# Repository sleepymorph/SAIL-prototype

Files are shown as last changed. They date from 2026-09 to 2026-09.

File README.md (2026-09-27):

<p align="center">
<picture>
  <source media="(prefers-color-scheme: dark)" srcset="LOGO/black.png">
  <source media="(prefers-color-scheme: light)" srcset="LOGO/white.png">
  SAIL THE PROTOTYPE LOGO
</picture>
 </p>

<h1 align="center"><b>SAIL THE PROTOTYPE</b></h1>

<div align="center">





</div>

---

**SAIL The Prototype** is a [DMP](https://en.wikipedia.org/wiki/Digital_media_player), an open-source project that aims to become a startup. This is not a basic digital media player, but also a multi-tool. It has 433MHZ CC1101, [Infrared LED](https://www.lcsc.com/product-detail/C18199783.html), and NFC functions(13.56MHZ). 
The STM32H723 is a powerful MCU for that project, I would say it is even an overkill. 

Hardware Architecture:
  1. Main Board: Houses the STM32, ESP32, Display, and user input interfaces
  2. NFC Board: Contains the NFC circuitry, CC1101(currently 433 MHZ only), and magnetic pogo pin connectors
  3. Infrared Board: Dedicated to IR Transceiver

The goal of the project is to combine multi-tool device with a music player, making you less addicted and helps you to escape social media & algorithms(bad ones).

|*MAIN Board* Top Component Layer |*MAIN Board* Bottom Component Layer |  
|  :--- | :--- |
| |  |

---

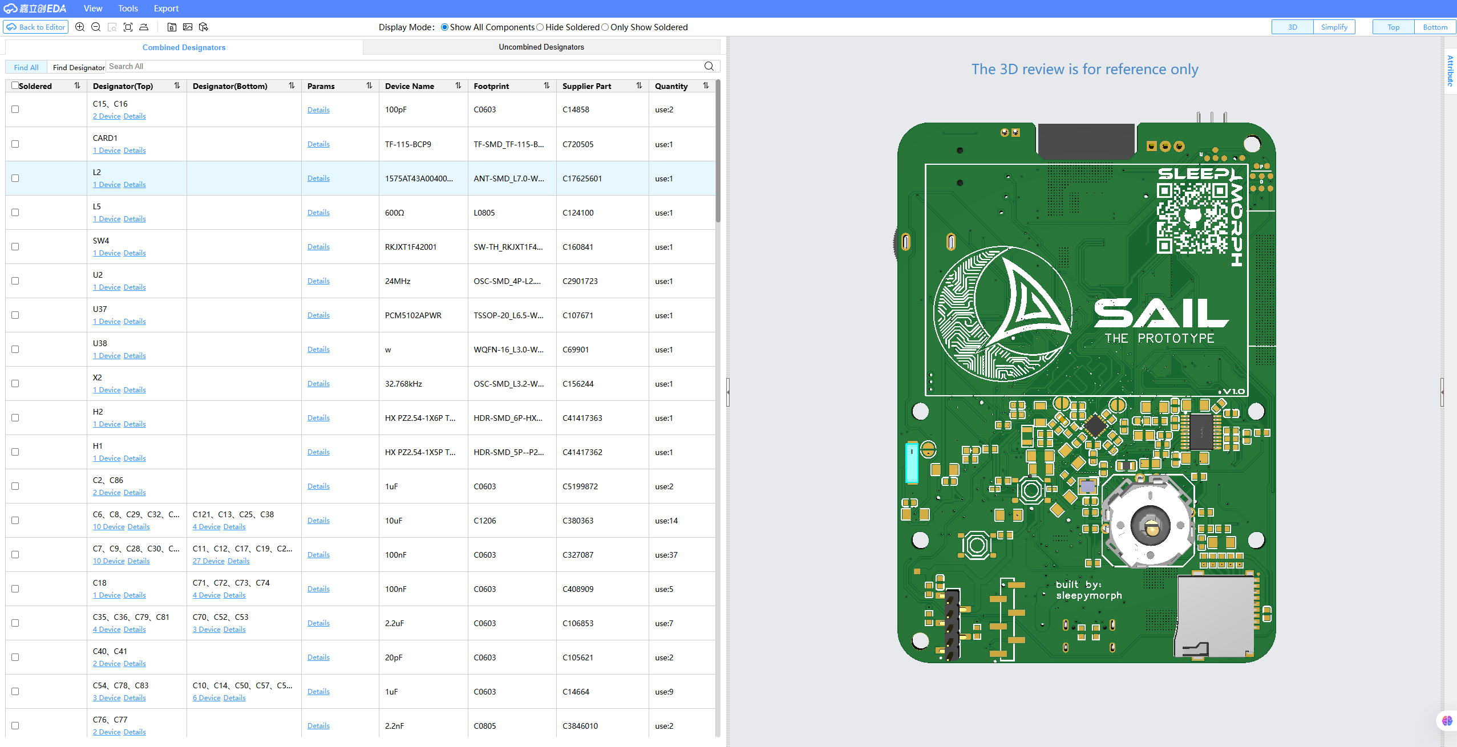
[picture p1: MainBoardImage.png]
Click me! (https://sail-mocha.vercel.app)

<p align="center">
    <b>Click the picture to see MAIN Board IBOM!</b>
  </a>
</p>

---

So, lets get into the details. First of all, lets talk about what you see here the most, to be exact - the user input devices.

The most valuable thing you can see here is probably the big [encoder](https://www.lcsc.com/product-detail/C160841.html). The encoder is pretty cool, its being used widely, especially at the automotive solutions. 

Its a 5-way button + encoder functions, to be exact its going 5 directions(X+, Y+, X-, Y-), pressing down, scrolling phase A and B. Next thing are 2 buttons, I still have no clue what I will use them for, but probably next song - previous song.

The most hidden, but probably the coolest thing of the device is the [thumb potentiometer](https://www.lcsc.com/product-detail/C351175.html), its placed at the left edge of the board, next to the left end to the display. 

---
<h1 align="center"><b>NFC Board</b></h1>

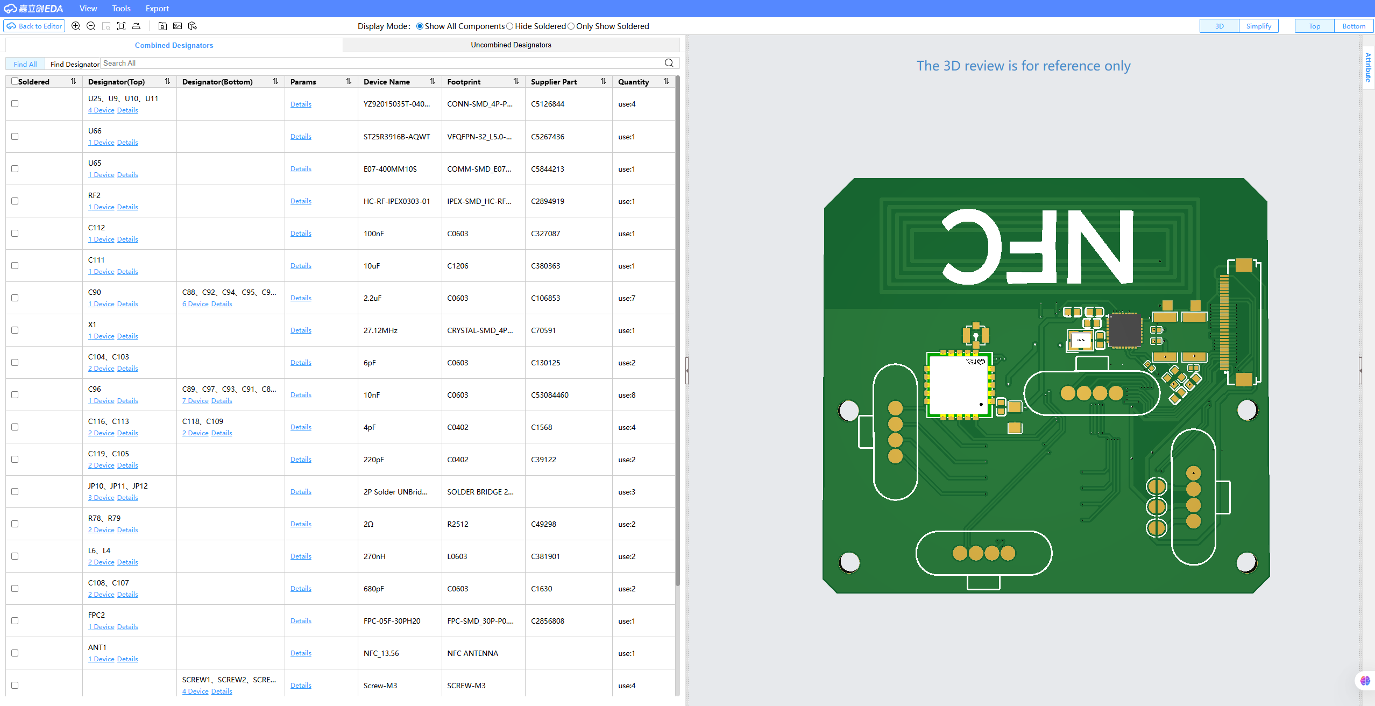
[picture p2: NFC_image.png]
Click me! (https://ibom-nfc.vercel.app/)

<p align="center">
    <b>Click the picture to see the NFC PCB IBOM!</b>
  </a>
</p>

--- 

NFC Board that contains half out of all of the functionality of the device --

It has NFC, CC1101 *433 MHz only yet*, and as a juicy cherry on a chocolate dry cake -
magnetic pogo pins for a breakout board. Here is the pinout if you would like to make a breakout board 

Untitled-2026-04-23-1610 excalidraw

| Pin on the board| IO on the ESP32|
| --- | --- |
| CS1: | IO32 |
| CS2: | IO33 |
| CS3: | IO4  |
| CS4: | IO15 |
| | |
| MOSI: | IO23 |
| MISO: | IO19 |
| SCK:  | IO18 |
| CS: | - |
| | |
| SDA: | IO21 |
| SCL: | IO22 |
---
<h1 align="center"><b>Infrared board</b></h1>

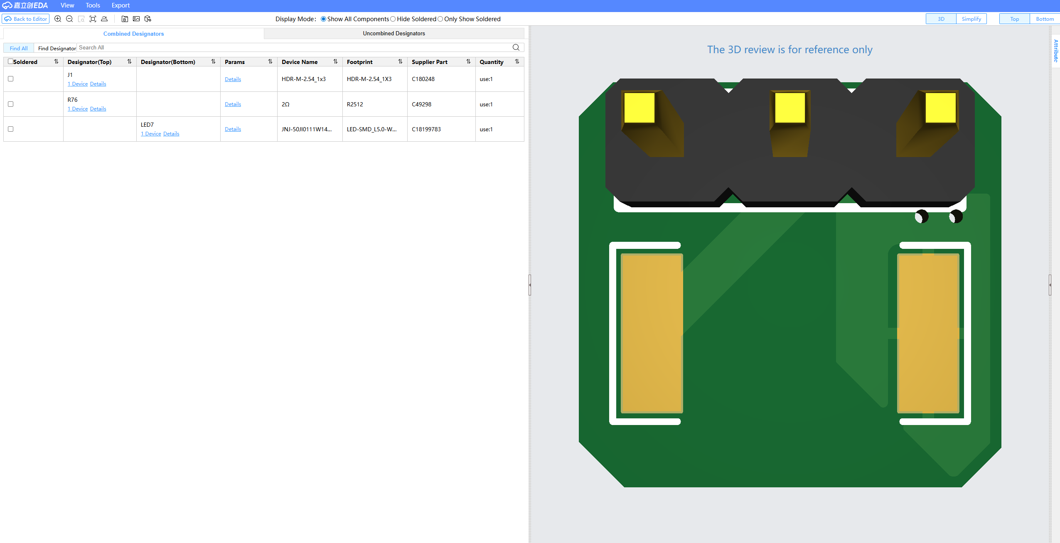
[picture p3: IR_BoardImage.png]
Click me! (https://ibom-ir.vercel.app/)

<p align="center">
    <b>Click the picture to see the Infrared PCB IBOM!</b>
  </a>
</p>

---

I couldnt find any good IR Transceiver which was right angled, so instead I found a really good SMD 5050 LED, its powerful enough to remote something from the distance of 15m *by my calculations*

---
# 3D Design:

Here is an image how it looks from the side, I explained a big rectangular right there and a strange looking knob right there too


---

# Fusion360 Render:



**The 3D files are in the Release folder since GitHub didnt want to accept files >25MB, there are 2 files, a Knob and fully assembled PCB(No casing yet)**

---

<h1 align="center"><b>More details and summary</b></h1>

| **Feature** | **Details** |
|---|---|
| **Main MCU** | STM32H723 as a main MCU that does all the work |
| **Secondary MCU** | ESP32-WROVER-IE(16MB) for BlueTooth headphones and pogo pin connectors(IOs) |
| **2.4" IPS TFT Display** | 2.4" IPS Display connected via FPC, 8080 16-bit protocol. [BuyDisplay](https://www.buydisplay.com/2-4-inch-ips-240x320-tft-lcd-display-capacitive-touch-screen) |
| **Multi-Tool features** | [NFC Module](https://www.lcsc.com/product-detail/C5267436.html), CC1101 *433 MHz ONLY*, IR Transceiver, Receiver |
| **RTC** | BS-CR2032-8 battery slot for [RTC functionality](https://www.lcsc.com/product-detail/C9866.html), and MAX-M10S-00B(GPS component) for RTC Syncing |
|	~~**Metal Body**~~ | ~~Aluminium front and back plate; 3D-printed middle section~~ *plan for future* |
| **Power and file transmitting** | USB-C Port which allows high speed data transfer(up to 50MB/s) with help of [USB3300](https://www.lcsc.com/product-detail/C108954.html) , and of course power delievery |
| **Battery Type** | 2500mAh Li-Po battery, 505065, [Aliexpress](https://www.aliexpress.com/item/1005009908189503.html) |
| **Battery Life** | ~8 hours idle, 4-5 hours typical usage |
| **Battery Voltage Measurement** | ADC Technology, connected to pin PA0 of STM32H7 |
| **Magnet on Back Plate of NFC Board(Pogo pins)** | [4x 4-Pin Pogo pin connector](https://www.lcsc.com/product-detail/C5126844.html) is a female version. For a breakout board you would need this [magnetic connector](https://www.lcsc.com/product-detail/C5126845.html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)  |
| **Audio components** | [PCM5102APWR](https://www.lcsc.com/product-detail/C107671.html) as a DAC, [TPA6132A2RTER](https://www.lcsc.com/product-detail/C69901.html) as an AMP and a [PJ-327A 5JJ](https://www.lcsc.com/product-detail/C668605.html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) as a jack 3.5mm connector for headphones. |  
| **Dimensions** | 70x100x25mm(W, L, H) which I find pretty solid(Only the PCB Assembled size), but I assume with a casing it would be with casing around 74x104x29mm(W, L, H)|
---

## .IOC


---

Questions or need more info? Reach out to me!\
Discord: **Sleepymorph**\
Telegram: **@ifyouask3d**

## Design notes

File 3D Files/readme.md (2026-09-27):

Assembled_PCB.rar contains a fully assembled PCB with no enclosure -- it has a knob, battery, 3 assembled boards and you can take a look at dimensions ^_^ 

ImageToStl com_Assembled_PCB stl

  1. 3D_NFC_*** - step file of NFC Board
  2. 3D_PCB5_*** - step file of IR Board
  3. MainPCB.zip - contains step file of Main Board

ImageToStl com_3D_PCB_MyOwnMP3_2026-04-27+(1) step

ImageToStl com_3D_NFC_2026-04-27 step

ImageToStl com_3D_PCB5_2026-04-27 step

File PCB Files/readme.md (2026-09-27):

This is a folder, containing a .zip file and .epcb
.zip file is to import the PCB to altium, and .epcb is a source file of the main PCB

Actually, .zip file(Altium) contains every file of the project, such as .schdoc and .pcbdoc

PCB_MyOwnMP3.pcbdoc - Main PCB Board
NFC.pcbdoc - NFC Board
PCB5.pcbdoc - IR Board

About .epcb I have no clue what you should do with it, but I have tested importing altium files into my EasyEDA Pro, and that worked quite well


Everything is good except the net port labels, I have no clue what happened to them:


Everything is also broken a little by little - the font didnt save, there is some strange PCB frame, some unknown 3D models, tho its not like that:


And there are 15650 DRC mistakes ...
Tho to fix all it takes is to recreate the ground plane 


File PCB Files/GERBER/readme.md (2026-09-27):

Gerber files here!

Explanation: 
  1. Gerber_PCB_MyOwnMP3_*** - Main Board
  2. Gerber_NFC_*** - NFC Board
  3. Gerber_PCB5_*** - IR Board

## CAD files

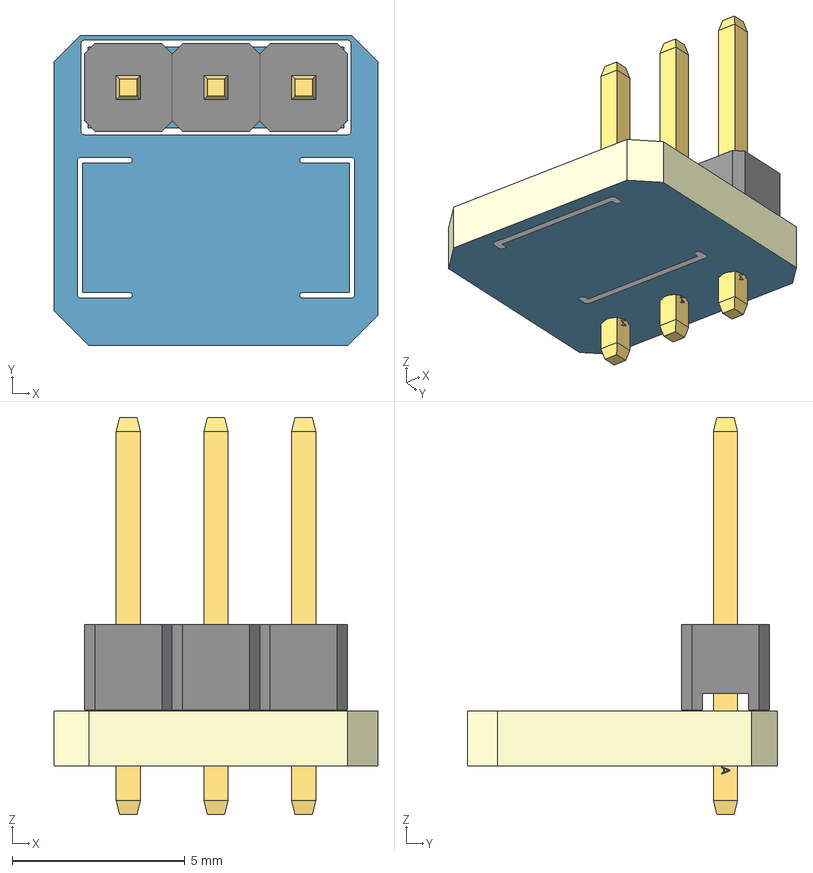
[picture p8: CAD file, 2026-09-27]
3D Files/3D_PCB5_2026-04-27.step
9.37 x 8.99 x 11.5 mm
Board~4CEo
TopCopper~4CEo
BottomCopper~4CEo
TopSilkscreen~4CEo
BottomSilkscreen~4CEo
TopFpcStiffener~4CEo
BottomFpcStiffener~4CEo
HDR-M-2.54_1X3~HDR-M-2.54_1x3~4CEo

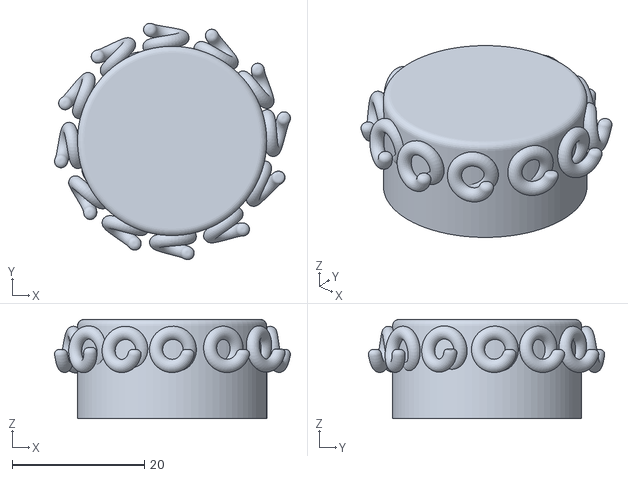
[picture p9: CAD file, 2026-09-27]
3D Files/Knob.stl
35.6 x 35.7 x 15.0

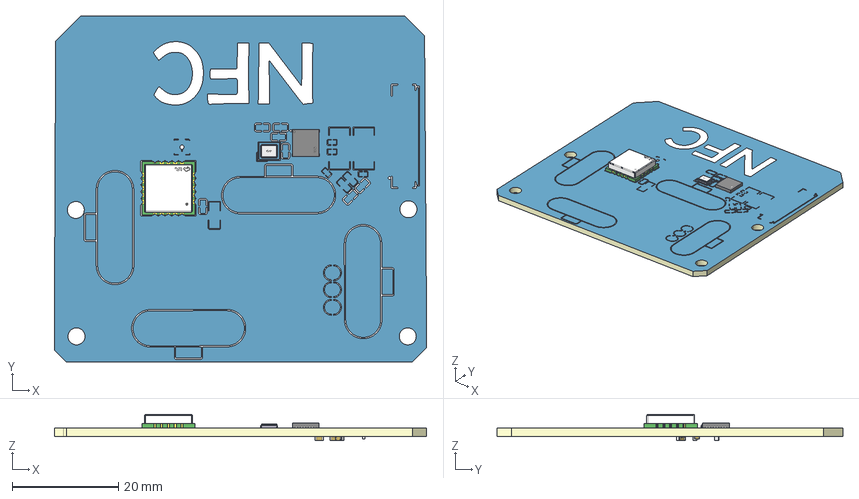
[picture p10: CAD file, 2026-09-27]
3D Files/3D_NFC_2026-04-27.step
70.0 x 65.0 x 4.92 mm
Board~R6V8
TopCopper~R6V8
BottomCopper~R6V8
TopSilkscreen~R6V8
BottomSilkscreen~R6V8
TopFpcStiffener~R6V8
BottomFpcStiffener~R6V8
C0603~C0603_L1.6-W0.8-H0.8~R6V8 x 3
C0402~C0402_L1.0-W0.5-H0.5~R6V8
CRYSTAL-SMD_4P-L3.2-W2.5-BL~CRYSTAL-SMD_4P-L3.2-W2.5-BL~R6V8
VFQFPN-32_L5.0-W5.0-P0.50-TL-EP3.5~VFQFPN-32_ L5.0-W5.0-P0.50-TL-EP3.5~R6V8
COMM-SMD_E07-400MM10S~COMM-SMD_E07-400MM10S~R6V8

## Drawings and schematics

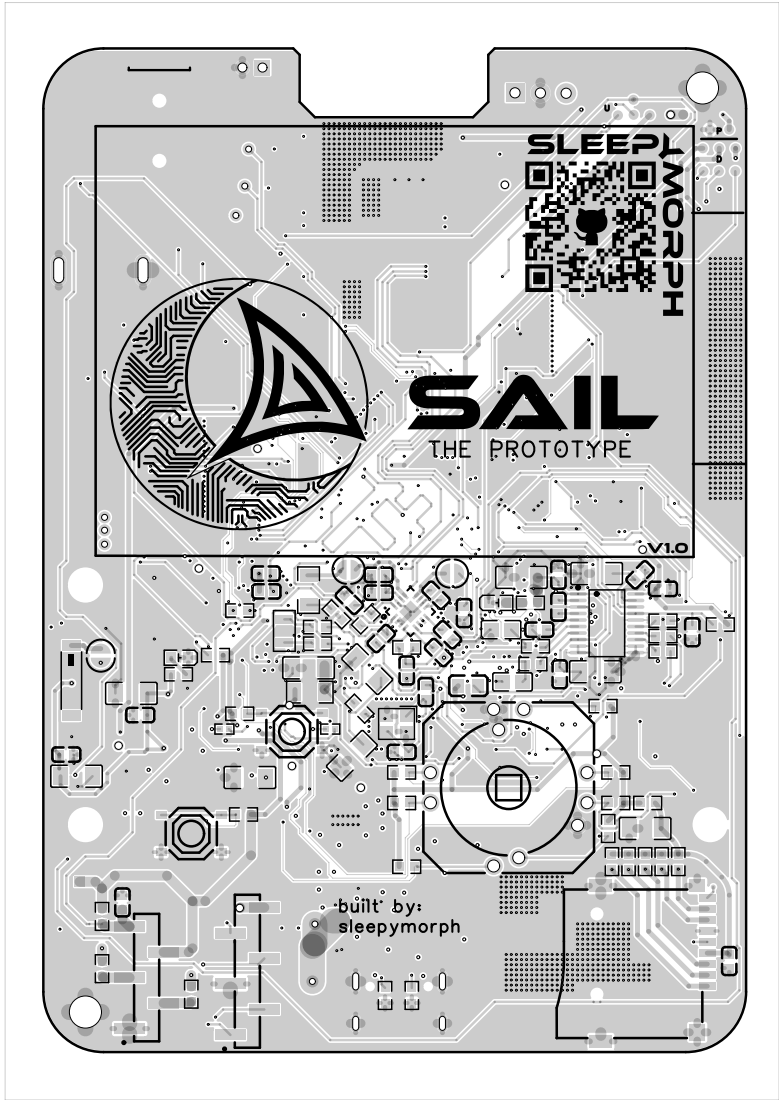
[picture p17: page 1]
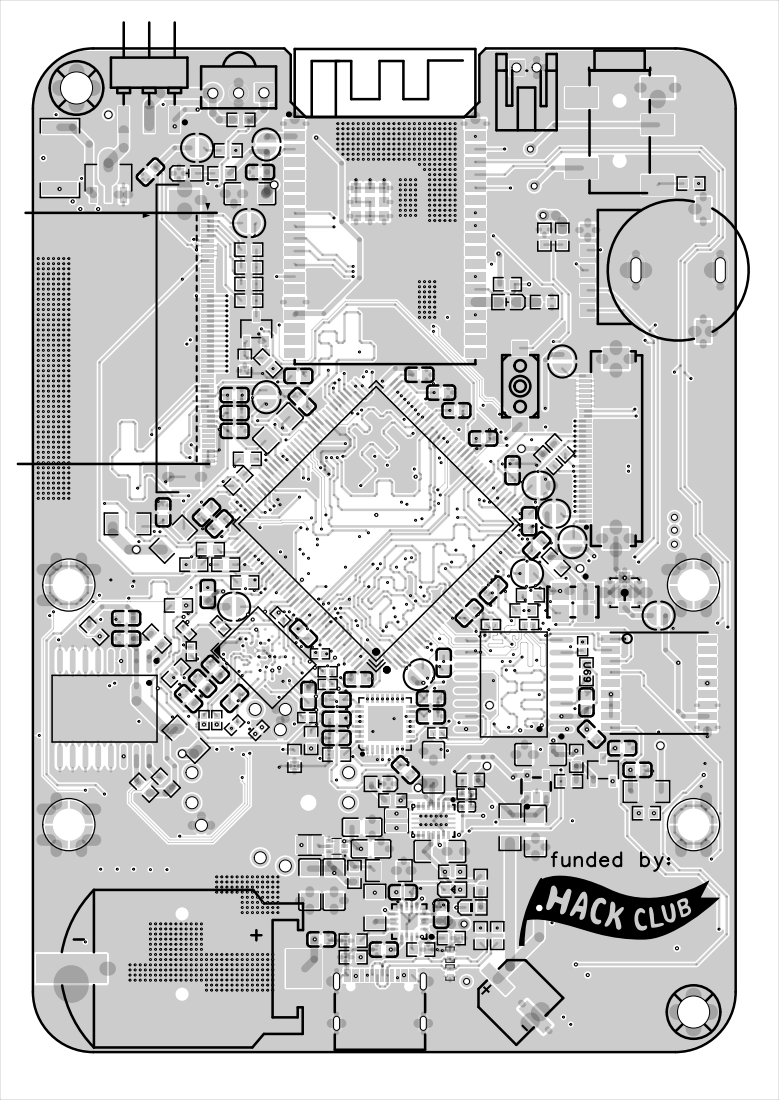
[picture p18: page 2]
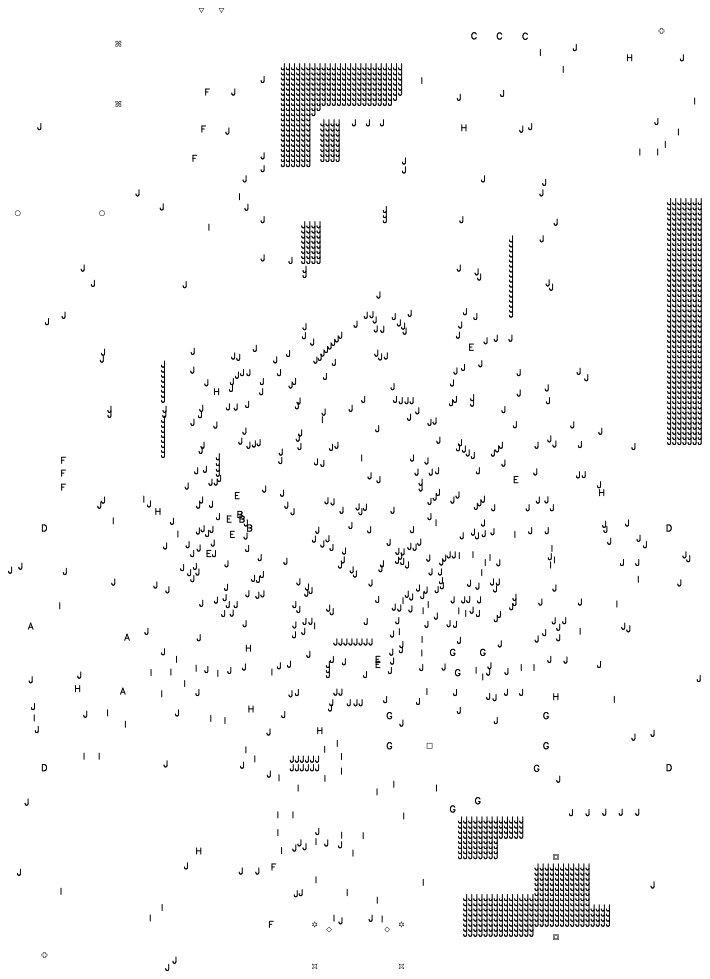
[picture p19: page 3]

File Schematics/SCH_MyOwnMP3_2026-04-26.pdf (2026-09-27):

VDD 72 PB12 73 PB13 74 PB14 75 PB15 76 PD8 77 PD9 78 PD10 79 PD11 80 PD12 81 PD13 82 VSS 83 VDD 84 PD14 85 PD15 86 PG2 87 PG3 88 PG4 89 PG5 90 PG6 91 PG7 92 PG8 93 VSS 94 VDD33USB 95 PC6 96 PC7 97 PC8 98 PC9 99 PA8 100 PA9 101 PA10 102 PA11 103 PA12 104 PA13 105 VCAP 106 VSS 107 VDD 108 PA14 109 PA15 110 PC10 111 PC11 112 PC12 113 PD0 114 PD1 115 PD2 116 PD3 117 PD4 118 PD5 119 VSS 120 VDD 121 PD6 122 PD7 123 PG9 124 PG10 125 PG11 126 PG12 127 PG13 128 PG14 129 VSS 130 VDD 131 PG15 132 PB3 133 PB4 134 PB5 135 PB6 136 PB7 137 BOOT0 138 PB8 139 PB9 140 PE0 141 PE1 142 PDR_ON 143 VDD 144

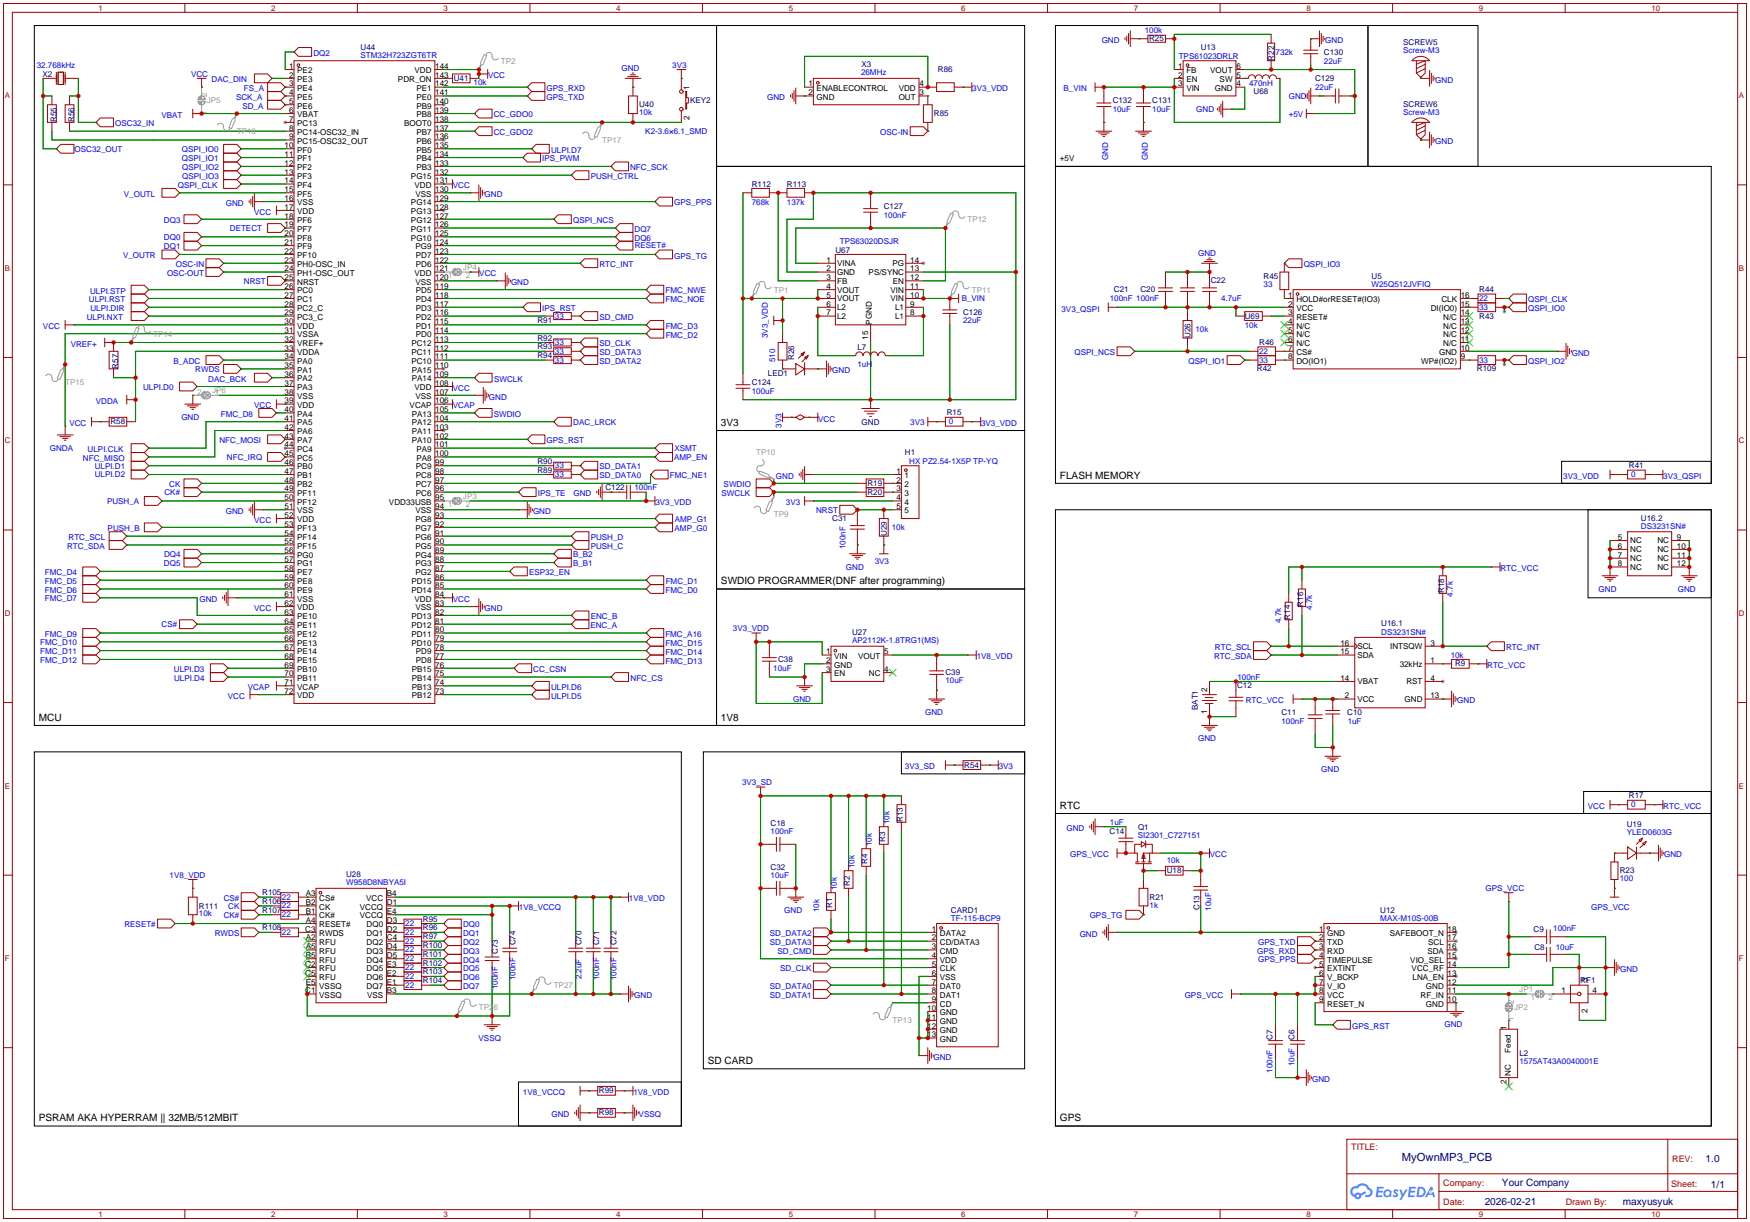
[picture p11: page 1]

VIN 10 VIN 11 EN 12 PS/SYNC 13 PG 14 PGND 15

SWDIO PROGRAMMER(DNF after programming)

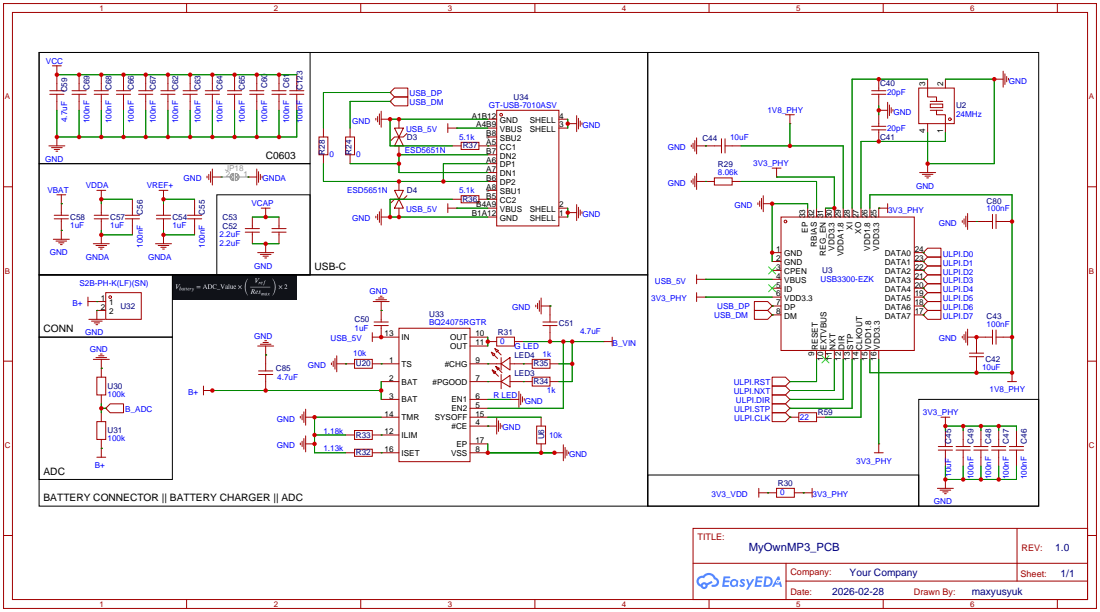
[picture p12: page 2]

BATTERY CONNECTOR || BATTERY CHARGER || ADC

## C29 10uF

## C37 10uF

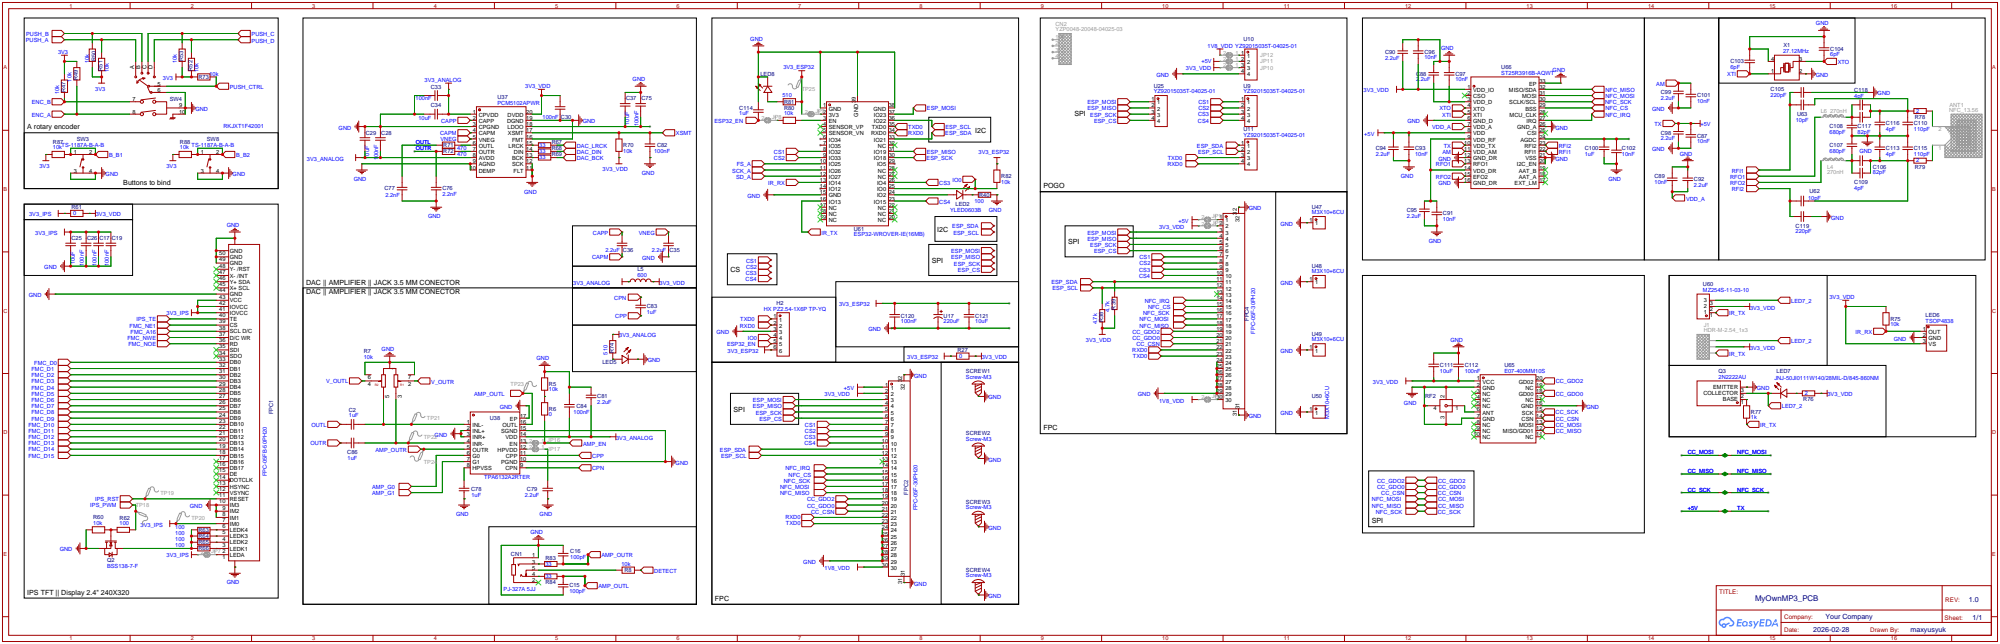
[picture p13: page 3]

NC 19 NC 18 NC 17 IO13 16 GND 15 IO12 14 IO14 13 IO27 12 IO26 11 IO25 10 IO33 9

DAC || AMPLIFIER || JACK 3.5 MM CONECTOR

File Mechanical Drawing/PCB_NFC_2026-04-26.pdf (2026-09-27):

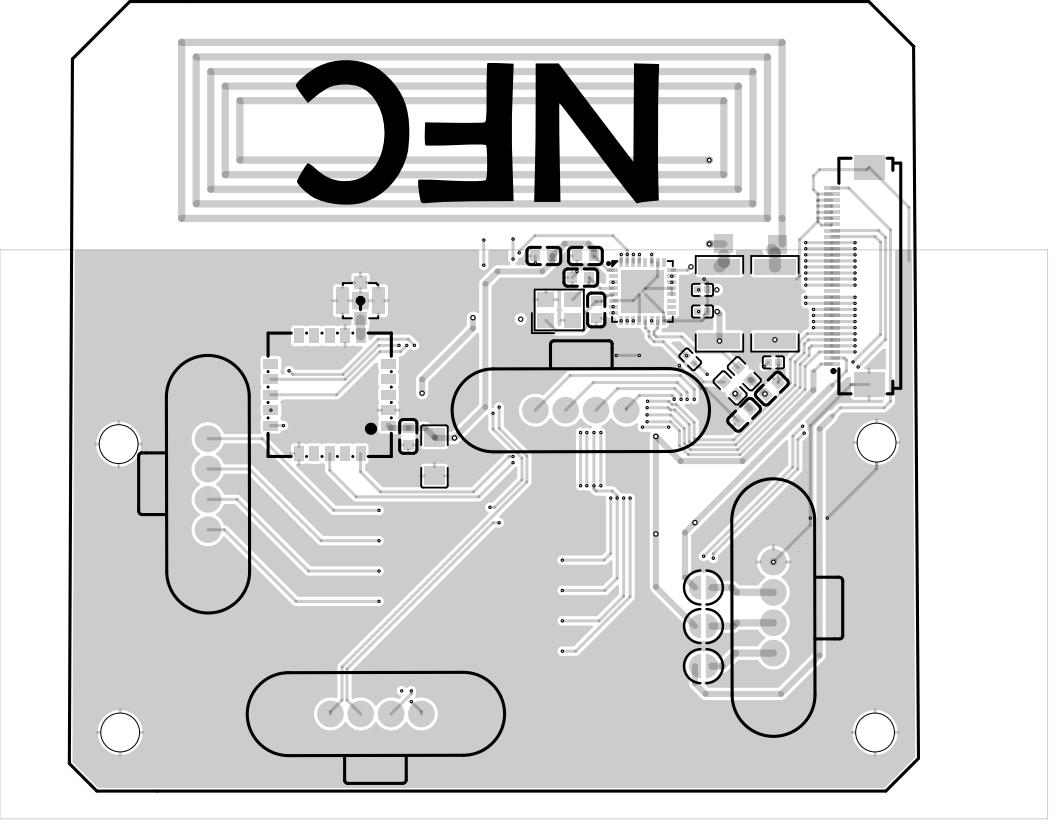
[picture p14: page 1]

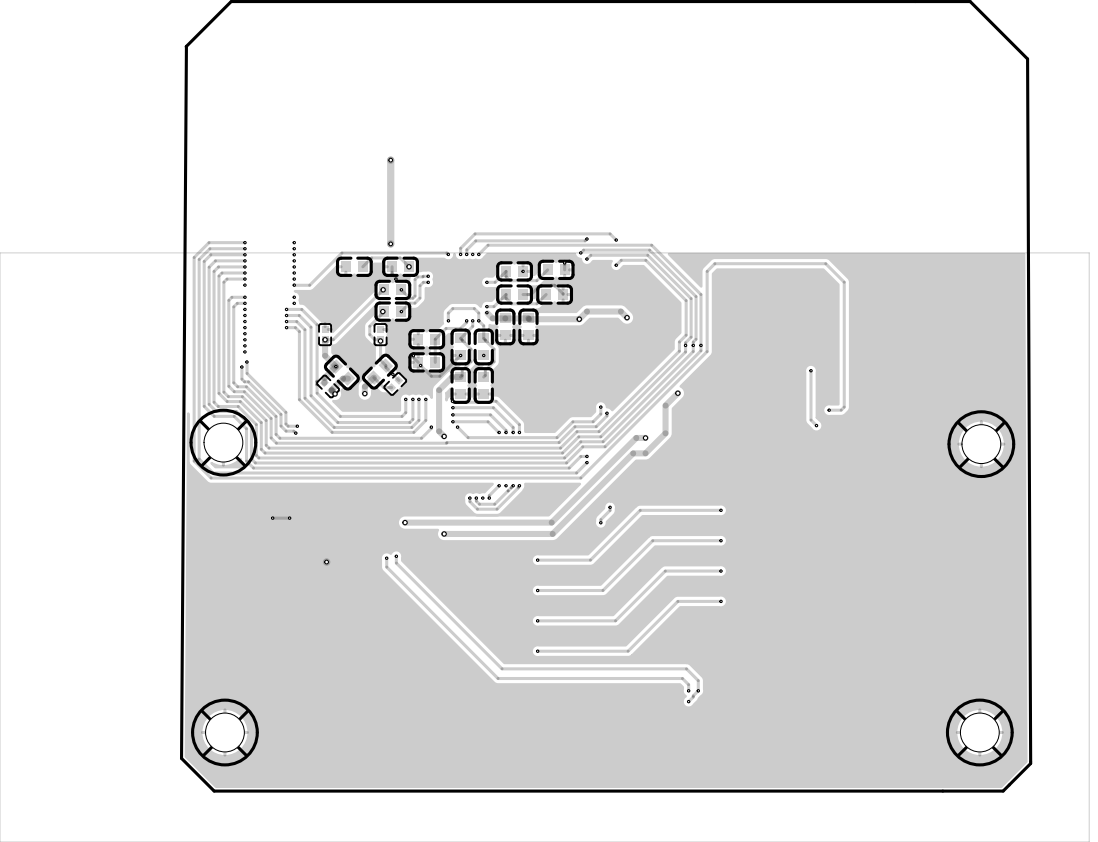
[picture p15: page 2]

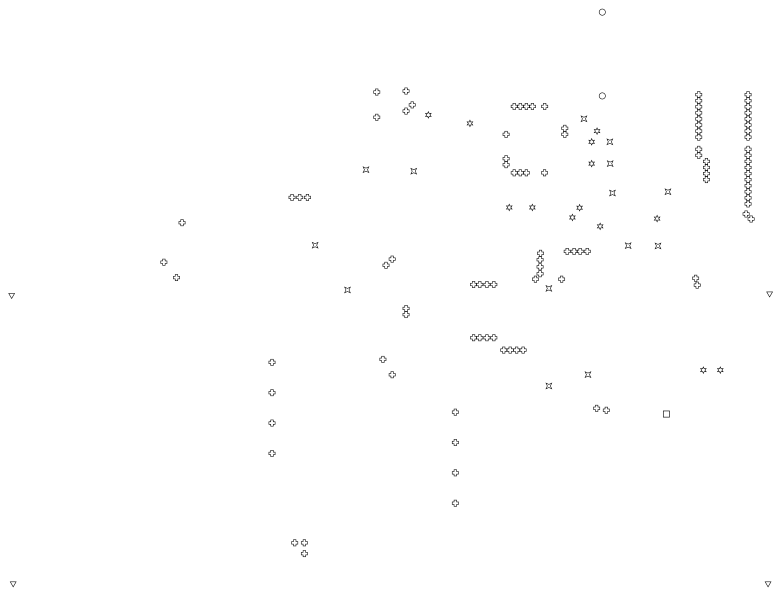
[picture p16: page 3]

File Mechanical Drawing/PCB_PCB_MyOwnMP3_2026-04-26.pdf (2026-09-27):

## SLEEP YMORPH

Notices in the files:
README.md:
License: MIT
